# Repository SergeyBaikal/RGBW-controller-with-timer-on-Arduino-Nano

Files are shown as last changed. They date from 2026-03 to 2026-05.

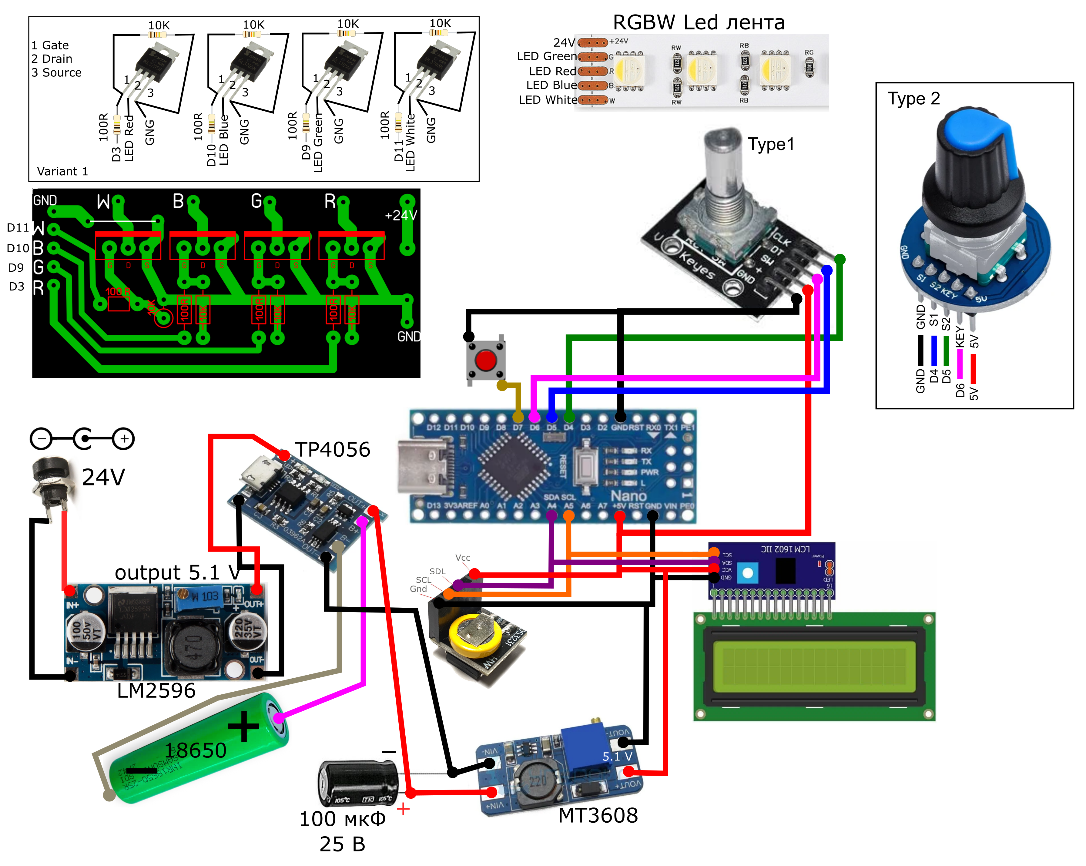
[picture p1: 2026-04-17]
Scheme_with_battery.png

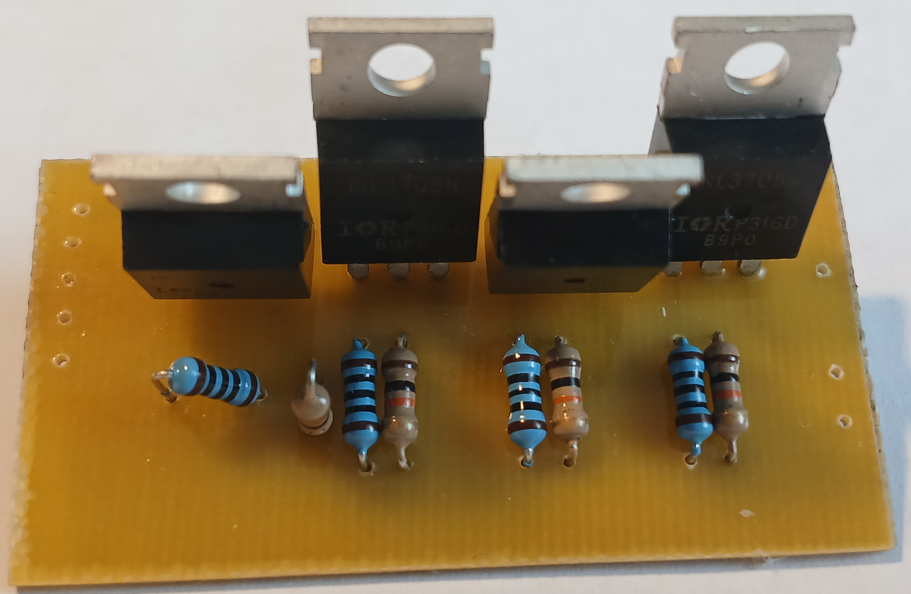
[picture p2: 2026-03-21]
Fig. S1.jpg

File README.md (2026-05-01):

# RGBW controller with timer on Arduino Nano

# 1. ОПИСАНИЕ УСТРОЙСТВА

Данное устройство предназначено для управления RGBW светодиодной лентой (12-24В) по заранее заданной программе. Контроллер автоматически меняет цвета ленты (Красный, Зеленый, Синий, Белый) в заданной последовательности и с заданной длительностью, основываясь на показаниях встроенных часов реального времени (RTC).

**Основные возможности:**
*   Автоматическая смена 4-х цветов (RED, GREEN, BLUE, WHITE) и выключения (Темнота «DARK») по расписанию.
*   Возможность пропуска ненужных шагов (SKIP).
*   Раздельная регулировка яркости для каждого цвета (0-255).
*   Работа циклически или однократно.
*   Интуитивное управление с помощью энкодера.
*   LCD 1602 дисплей с настраиваемым отключением подсветки.
*   Сохранение всех настроек в энергонезависимую память (EEPROM).
*   Высокая настраиваемая частота ШИМ (до 31.2 kHz в режиме Phase-correct PWM и до 62.5 kHz в режиме Fast PWM) для исключения мерцания ленты.

# 2. КОМПЛЕКТУЮЩИЕ И СХЕМА ПОДКЛЮЧЕНИЯ

1.  Arduino Nano
2.  LCD 1602 дисплей с I2C адаптером
3.  Модуль часов реального времени DS3231
4.  Энкодер (с кнопкой)
5.  MOSFET для RGBW ленты:
    *   В корпусе TO-220: IRL3705N, IRLZ44N, IRF3205 – лично использованы мной в этом проекте. Можно и другие, смотрите характеристики.
6.  Блок питания: (12/24V). Важно настроить понижающий и повышающий преобразователи при выбранном вольтаже до (!) подключения питания к Arduino (см. рисунок - схему подключения).
7.  Кнопка тактовая для сброса настроек (по необходимости, можно не ставить)
8.  Аккумулятор 18650 (по необходимости, можно не устанавливать)
9.  Плата зарядки аккумулятора TP4056 (по необходимости, можно не устанавливать)
10. Понижающий модуль с 12/24 вольт до 5 вольт (LM2596)
11. Повышающий модуль MT3608. Если хотите сделать чтобы Arduino продолжало работать, когда отключат электроэнергию (по необходимости, можно не устанавливать).

## Схема подключения

**Важно!** Устройство не коммутирует напряжение ленты напрямую. Arduino управляет MOSFET модулем, который, в свою очередь, включает и выключает ленту (т.е. на пине управления будет 0 В или 5 В).

**Таблица 1. Компоненты и пины подключения.**

| Компонент | Пин компонента | Пин Arduino Nano | Примечание |
| :--- | :--- | :--- | :--- |
| **Энкодер** | CLK | D4 | |
| | DT | D5 | |
| | SW (кнопка) | D6 | Подтяжка к GND при нажатии |
| | VCC | 5V | |
| | GND | GND | |
| **DS3231 (RTC)** | SDA (D) | A4 (SDA) | I2C линия |
| | SCL (C) | A5 (SCL) | I2C линия |
| | VCC (+) | 5V | |
| | GND (-) | GND | |
| **LCD I2C** | SDA | A4 (SDA) | I2C линия (общая с RTC) |
| | SCL | A5 (SCL) | I2C линия (общая с RTC) |
| | VCC | 5V | |
| | GND | GND | |
| **Кнопка сброса** | Один контакт | D7 | |
| | Второй контакт | GND | Замыкает на GND при нажатии |
| **MOSFET модуль** | Красный канал (R) | D3 | ШИМ |
| | Зеленый канал (G) | D9 | ШИМ |
| | Синий канал (B) | D10 | ШИМ |
| | Белый канал (W) | D11 | ШИМ |
| | GND | GND | Общий GND с Arduino |

# 3. СБОРКА УСТРОЙСТВА

1.  **Подготовка:** Ознакомьтесь со схемой подключения. Убедитесь, что все компоненты исправны.
2.  **Монтаж:** Соедините все компоненты согласно схеме (см. схему).

# 4. ПРОШИВКА КОНТРОЛЛЕРА

**Важно!** Отключайте внешнее питание при загрузке скетча (блок питания и аккумулятор, если подключены).

1.  Установите Arduino IDE на ваш компьютер.
2.  Установите необходимые библиотеки. Для этого откройте менеджер библиотек (Скетч -> Подключить библиотеку -> Управлять библиотеками...) и найдите/установите следующие библиотеки:
    *   `LiquidCrystal I2C v.2.0.0` (by Frank de Brabander)
    *   `GyverDS3231Min v.1.2.0` (by AlexGyver)
    *   `EncButton v.3.7.4` (by AlexGyver)
    *   `GyverPWM v.1.6.1` (by AlexGyver)
3.  Подключите Arduino Nano к компьютеру через USB.
4.  В Arduino IDE выберите настройки:
    *   **Плата:** Инструменты -> Плата -> Arduino Nano
    *   **Процессор:** Инструменты -> Processor -> ATmega328P (Old Bootloader) (чаще всего)
    *   **Порт:** Инструменты -> Port -> COM... (нужный порт)
5.  Скопируйте код в окно Arduino IDE или откройте файл с расширением `.ino`. Примечание: файл ino должен лежать в одноименной папке, например RGBW.ino должен лежать в папке RGBW. 
6.  Нажмите кнопку **"Загрузить"** (стрелка вправо). Дождитесь окончания загрузки.
7.  Отключить от USB (!) если хотите сразу подключить к блоку питания, но можно не подключать блок питания (и аккумулятор), а потестировать работоспособность энкодера и управление через меню. 

* Чтобы инвертировать поворот энкодера, нужно просто сменить знак:
  `int8_t change = -enc.dir();`  // Сейчас так, можно убрать `-`, чтобы инвертировать

# 5. ПЕРВОЕ ВКЛЮЧЕНИЕ И НАСТРОЙКА

1.  Подайте питание на устройство.
2.  На экране появится заставка с версией прошивки, затем устройство перейдет в главное меню.
3.  **Важно:** если часы реального времени (RTC) не обнаружены, на экране появится ошибка **"RTC ERROR!"**. Проверьте подключение модуля и перезагрузите устройство (путём отключения питания Arduino).
4.  **Текущее время установится автоматически при компиляции, если нет, то:**
    *   Вращайте энкодер, чтобы выбрать пункт **«CLOCK»** в главном меню.
    *   Нажмите на кнопку энкодера, чтобы войти в подменю.
    *   Нажмите еще раз, чтобы начать редактирование часов. Мигающий символ **«H»** показывает, что редактируются часы. Вращайте энкодер для установки значения.
    *   Нажмите кнопку еще раз. Теперь мигает **«M»** — редактируются минуты. Вращайте энкодер.
    *   Нажмите кнопку для подтверждения и выхода из режима редактирования.
5.  Настройте цепочку цветов, их яркость и длительность (см. следующий раздел).

# 6. ИНТЕРФЕЙС И НАВИГАЦИЯ

Управление устройством осуществляется с помощью одного энкодера. Он имеет три основных действия:

*   **ВРАЩЕНИЕ:** Перемещение курсора в меню (вверх/вниз, влево/вправо) или изменение значения параметра.
*   **КОРОТКОЕ НАЖАТИЕ (КЛИК):** Вход в подменю, выбор пункта, начало/конец редактирования параметра.
*   **ДОЛГОЕ НАЖАТИЕ (УДЕРЖАНИЕ ~1 сек):** Выход из текущего меню на уровень выше или остановка активного режима RUN.

**Структура навигации:**
*   **Главное меню:** Список доступных разделов. Вращайте энкодер для выбора пункта, нажмите для входа.
*   **Подменю:** Список параметров внутри раздела. Вращайте энкодер для выбора параметра, нажмите для редактирования.
*   **Режим редактирования:** Значение параметра мигает. Вращайте энкодер для изменения значения. Нажмите для сохранения и выхода.

# 7. ДЕТАЛЬНОЕ ОПИСАНИЕ МЕНЮ

Главное меню состоит из 8 пунктов. Текущий пункт отмечен символом **«>»** слева. В нижней строке отображается следующий пункт для удобства навигации.

### 1. CHAIN (Цепочка цветов)
Здесь настраивается последовательность из 6 шагов.
*   **На экране:** `1#: R` (означает: шаг №1, цвет R).
*   **Редактирование:** Выберите нужный шаг (`1#`-`6#`) вращением, нажмите кнопку. Каждое нажатие меняет цвет по циклу:
    *   `R` (Красный)
    *   `G` (Зеленый)
    *   `B` (Синий)
    *   `W` (Белый)
    *   `D` (DARK, темнота/Выкл)
    *   `X` (SKIP, пропустить шаг)

### 2. BRIGHTNESS (Яркость)
Настройка яркости для каждого цвета индивидуально.
*   **На экране:** `R: 128` (означает: Красный канал, яркость 128).
*   **Редактирование:** Выберите канал (`R`, `G`, `B`, `W`) вращением, нажмите кнопку. Вращайте энкодер для изменения яркости от 0 до 255. Нажмите кнопку для сохранения. Во время редактирования выбранный цвет загорается для визуального контроля.

### 3. TIME (Длительность)
Установка времени работы для каждого шага цепочки.
*   **На экране:** `01:30 1#:R` (означает: 1 час 30 минут для шага №1 цвета R).
*   **Редактирование:** Выберите шаг (`1#`-`6#`) вращением, нажмите кнопку. Начните редактирование часов (мигает **«H»**), вращайте. Нажмите кнопку для перехода к минутам (мигает **«M»**), вращайте. Нажмите кнопку для сохранения.
*   **Примечание:** если для шага в меню «CHAIN» выбран цвет **«X»** (SKIP), его длительность автоматически устанавливается в **«00:00»** и не редактируется.

### 4. REPEAT (Повтор)
Определяет, будет ли цепочка цветов повторяться бесконечно.
*   **На экране:** **«YES»** или **«NO»**.
*   **Редактирование:** Нажмите кнопку для переключения значения.
    *   **«YES»:** после 6-го шага цикл начнется снова с 1-го.
    *   **«NO»:** после завершения 6-го шага работа остановится, лента погаснет.

### 5. CLOCK (Настройка часов)
Установка текущего времени на модуле DS3231.
*   **На экране:** **«SET CLOCK»** и текущее время (например, **«14:25»**).
*   **Редактирование:** Нажмите кнопку для входа в режим редактирования. Аналогично меню «TIME»: сначала редактируются часы, затем минуты.
*   Если RTC не обнаружен, на экране будет **«RTC ERROR»**.

### 6. TEST (Тест)
Быстрая проверка работоспособности ленты и подключения.
*   **Запуск:** Войдите в меню и нажмите кнопку. Устройство по очереди включит на 1 секунду каждый цвет (Красный, Зеленый, Синий, Белый), а затем погаснет.

### 7. DISPLAY (Дисплей)
Настройка таймера подсветки дисплея для экономии энергии.
*   **На экране:** текущий режим.
*   **Редактирование:** Нажмите кнопку для циклического переключения режимов:
    *   **«OFF»:** Подсветка всегда выключена.
    *   **«15MIN»:** Подсветка гаснет через 15 минут бездействия (вращения/нажатия энкодера).
    *   **«1HOUR»:** Подсветка гаснет через 1 час бездействия.
    *   **«ALWAYS»:** Подсветка всегда включена.

### 8. RUN (Запуск)
Основной режим автоматической работы по расписанию.
*   **Запуск:** Войдите в меню. Если RTC исправен, режим запустится автоматически.
*   **Экран RUN:**
    *   Верхняя строка: **«RUN 14:35»** (текущее время).
    *   Нижняя строка: **«01:23 3#:B»** (оставшееся время до смены цвета: 1 час 23 минуты, текущий шаг №3, цвет Синий).
*   **Во время работы:**
    *   **Клик:** показывает на 5 секунд всю цепочку цветов (например, **`R-G-B-W-D-X`**).
    *   **Удержание:** останавливает режим RUN и возвращает в главное меню.

Автоматика сама будет переключать цвета в заданное время, основываясь на времени старта шага и его длительности.

# 8. РЕЖИМ РАБОТЫ ПО РАСПИСАНИЮ (RUN)

Это сердце программы. Алгоритм работы:

1.  При входе в меню **«RUN»** фиксируется текущее время (минуты) как время старта первого шага (Step 1).
2.  Контроллер включает цвет, заданный для Step 1.
3.  Каждую минуту программа проверяет, сколько времени прошло с момента старта шага.
4.  Как только пройденное время становится равным или превышает заданную для этого шага длительность (из меню «TIME»), происходит автоматический переход к следующему шагу.
5.  Шаги, помеченные как **«X»** (SKIP), автоматически пропускаются (на них не тратится время).
6.  Если после завершения последнего шага параметр «REPEAT» установлен в **«YES»**, цикл начинается заново с шага 1. Если **«NO»** — режим RUN останавливается, лента гаснет.

# 9. СБРОС НАСТРОЕК

Если вы хотите вернуть все настройки (цепочку, яркость, время и т.д.) к предустановленным значениям:

1.  Убедитесь, что устройство включено.
2.  Нажмите и удерживайте тактовую кнопку, подключенную к пину D7 (Reset).
3.  На экране появится сообщение **«RESET MEMORY»**.
4.  Отпустите кнопку. Настройки будут сброшены, и устройство перезагрузится.

*Примечание: функцию сброса можно не использовать, я сделал её для себя, чтобы быстро возвращаться к первоначальным параметрам.*

**Предустановленные настройки:**
*   **Цепочка:** R, G, B, W, D, X
*   **Яркость всех цветов:** 128
*   **Длительность всех шагов:** 120 минут (v.1.8.4), 2 минуты (v.1.8.5)
*   **Repeat:** YES
*   **Подсветка:** 15MIN

# 10. ПРИМЕЧАНИЕ

* Проект писался полностью под себя, поэтому, вероятно, вы найдёте много недочётов т.к. выборка тестов небольшая. Тестировал на 2 сборках с новыми деталями. Если есть вопросы, задавайте, в том числе по чистке и улучшению скетча. 
* Кроме того, прикрепляю простой корпус в STL формате (сам корпус и дно), дисплей прикручивается мелкими винтами, остальное можно закрепить термоклеем, ардуино лучше прикрутить на мелкие саморезы, для оперативности загрузки скетчей.
* Посмотрите на рисунок Fig.S1 - нужно развести транзисторы друг относительно друга, чтобы стоки не касались.
* Файл Sprint-Layout так же прикрепляю, если кто-то захочет вытравить платку модуля для MOSFET.
* Писать можно сюда: poet1988@list.ru.
* Благодарю AlexGyver за уроки по ардуино на его сайте.

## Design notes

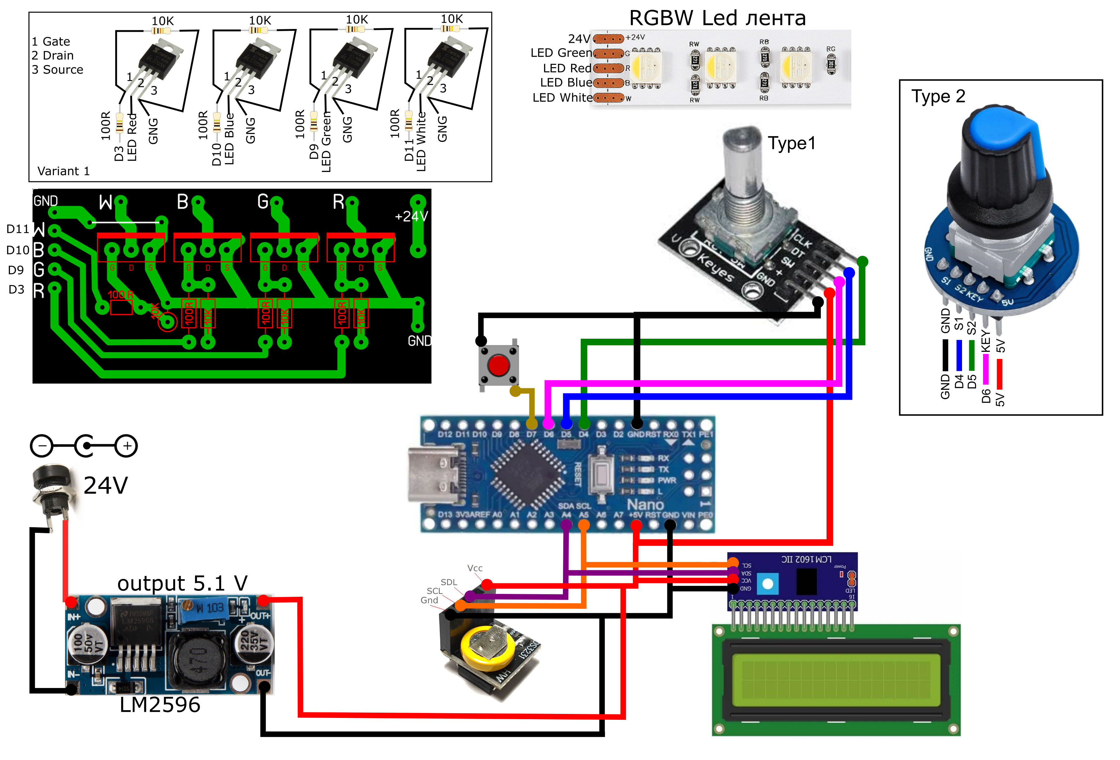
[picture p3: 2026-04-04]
Scheme_without_battery.png

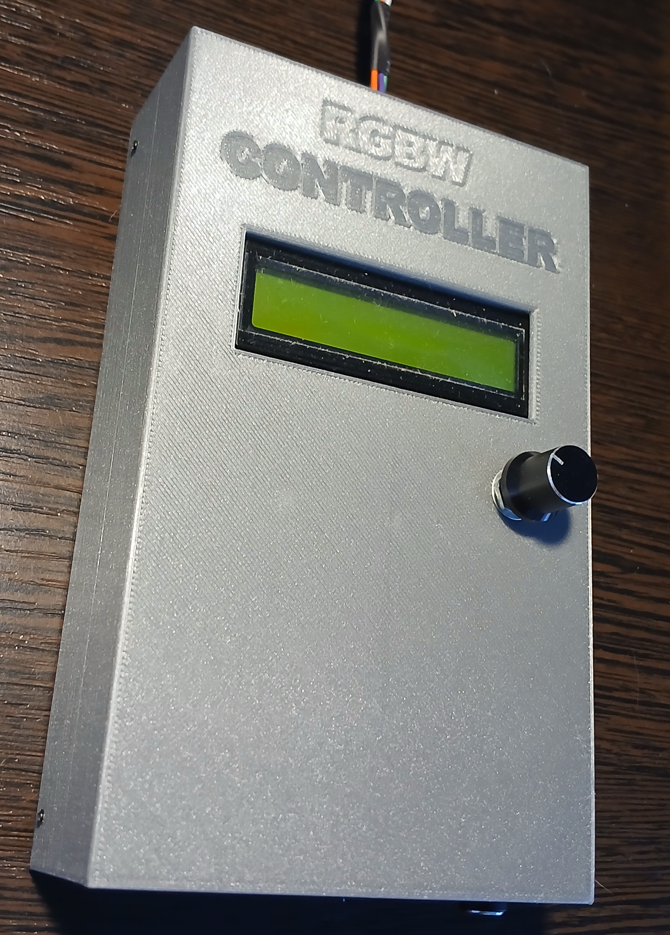
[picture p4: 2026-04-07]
RGBW.jpg

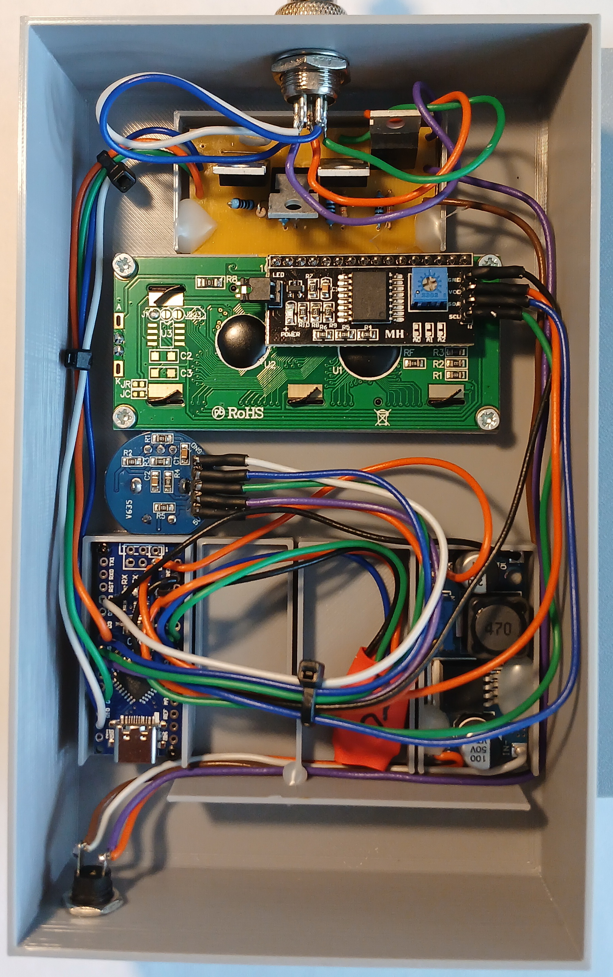
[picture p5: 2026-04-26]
Internal view.jpg

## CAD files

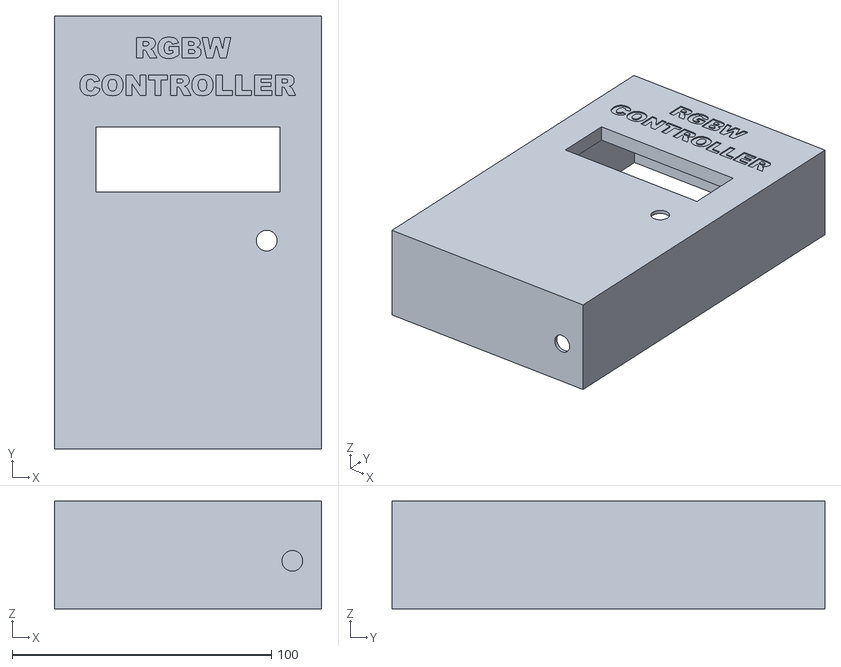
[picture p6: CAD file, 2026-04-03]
RGBW_box_avia.stl
103.0 x 167.0 x 41.5

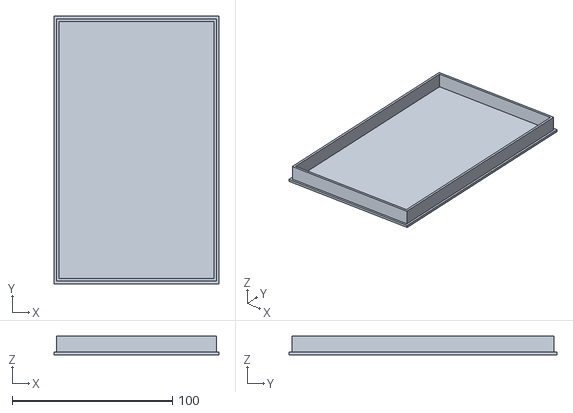
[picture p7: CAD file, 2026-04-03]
Bottom_avia_0.1.stl
103.0 x 167.0 x 11.6

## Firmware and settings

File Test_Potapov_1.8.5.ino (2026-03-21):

/*
  Управление RGBW лентой 24В через Arduino Nano
  с автоматической сменой цвета по расписанию
  Потапов С.А. poet1988@list.ru
  Версия 1.8.5 
  
  Библиотеки:
  - EncButton v3.7.4
  - GyverDS3231Min v1.2+
  - GyverPWM
*/

#include <Wire.h>
#include <LiquidCrystal_I2C.h>
#include <GyverDS3231Min.h>
#include <EncButton.h>
#include <EEPROM.h>
#include <GyverPWM.h>  

// =============== НАСТРОЙКИ КОМПИЛЯЦИИ ===============
#define EB_DEB_TIME 50
#define EB_CLICK_TIME 500
#define EB_HOLD_TIME 600
#define EB_STEP_TIME 200
#define EB_FAST_TIME 30
#define EB_TOUT_TIME 1000

// =============== НАСТРОЙКА ЧАСТОТЫ ШИМ ===============
// Выбор режима ШИМ:
// 0 - Fast PWM (максимальная частота, меньше мерцания)
// 1 - Phase-correct PWM (симметричный, меньше помех)
#define PWM_MODE 0

// Выбор предделителя (частоты):
// 1 - максимальная частота (62.5/31.4 кГц)
// 2 - средняя частота (7.8/4 кГц для Timer1, 8/4 кГц для Timer2)
// 3 - низкая частота (976/490 Гц для Timer1, 2к/980 Гц для Timer2)
#define PWM_PRESCALER 1

/*
   ТАБЛИЦА ЧАСТОТ ШИМ ДЛЯ ARDUINO NANO 
   _________________________________________________________________
  |       | Timer1 (пины 9 и 10) 8 bit | Timer2 (пины 3 и 11) 8 bit|
  |_______|____________________________|___________________________|
  |mode   | Phase-correct | Fast PWM   | Phase-correct | Fast PWM  |
  |_______|_______________|____________|_______________|___________|
  |1      | 31.4 kHz      | 62.5 kHz   | 31.4 kHz      | 62.5 kHz  |
  |2      | 4 kHz         | 7.8 kHz    | 4 kHz         | 8 kHz     |
  |3      | 490 Hz        | 976 Hz     | 980 Hz        | 2 kHz     |
  |_______|_______________|____________|_______________|___________|
  
  
*/

// =============== КОНСТАНТЫ И НАСТРОЙКИ ===============

const char FIRMWARE_VERSION[] = "1.8.5";

// Настройки дисплея
#define LCD_ADDR 0x27
#define LCD_COLS 16
#define LCD_ROWS 2

// Настройки энкодера
#define ENC_CLK 4      // D4 - CLK энкодера
#define ENC_DT 5       // D5 - DT энкодера 
#define ENC_SW 6       // D6 - SW энкодера (кнопка)

// Пины ШИМ
#define PIN_RED 3      // D3 - КРАСНЫЙ канал (Timer2)
#define PIN_GREEN 9    // D9 - ЗЕЛЁНЫЙ канал (Timer1)
#define PIN_BLUE 10    // D10 - СИНИЙ канал (Timer1)
#define PIN_WHITE 11   // D11 - БЕЛЫЙ канал (Timer2)

// Кнопка сброса
#define RESET_BUTTON 7

// Настройки EEPROM
#define EEPROM_SIZE 512
#define EEPROM_MAGIC 0xAA56
#define EEPROM_SAVE_DELAY 5000

#define MAX_STEPS 6
#define TIMEZONE 3
#define ENCODER_TYPE EB_STEP4_LOW

// =============== СТРУКТУРЫ ДАННЫХ ===============

enum Color {
  COLOR_RED,
  COLOR_GREEN,
  COLOR_BLUE,
  COLOR_WHITE,
  COLOR_DARK,
  COLOR_SKIP,
  COLOR_COUNT
};

struct Settings {
  uint16_t magic;
  uint8_t version;
  Color chain[MAX_STEPS];
  uint8_t brightness[4];
  uint16_t durations[MAX_STEPS];
  bool repeat;
  uint8_t backlightTimeout;
};

struct RunState {
  uint8_t currentStep;
  bool active;
  uint32_t stepStartUnix;
  
  RunState() : currentStep(0), active(false), stepStartUnix(0) {}
} runState;

struct Flags {
  uint8_t displayOn : 1;
  uint8_t rtcOk : 1;
  uint8_t settingsChanged : 1;
  uint8_t showChain : 1;
  uint8_t inSubMenu : 1;
  uint8_t editingValue : 1;
  uint8_t rtcMessageShown : 1;
  uint8_t rtcTimeValid : 1;
  uint8_t testRunning : 1;
} flags;

// =============== ГЛОБАЛЬНЫЕ ПЕРЕМЕННЫЕ ===============

LiquidCrystal_I2C lcd(LCD_ADDR, LCD_COLS, LCD_ROWS);
GyverDS3231Min rtc;
EncButton enc(ENC_CLK, ENC_DT, ENC_SW);

Settings settings;

enum MenuState {
  MENU_MAIN,
  MENU_CHAIN,
  MENU_BRIGHTNESS,
  MENU_TIME,
  MENU_CLOCK,
  MENU_REPEAT,
  MENU_DISPLAY,
  MENU_RUN,
  MENU_TEST
};

MenuState currentMenu = MENU_MAIN;
uint8_t menuCursor = 0;
uint8_t subMenuCursor = 0;
uint8_t editPart = 0;
uint8_t editHours = 0;
uint8_t editMinutes = 0;
uint8_t editValue = 0;

// Таймеры
unsigned long displayTimer = 0;
unsigned long saveTimer = 0;
unsigned long rtcCheckTimer = 0;
unsigned long runUpdateTimer = 0;
unsigned long runDisplayTimer = 0;
unsigned long testTimer = 0;
unsigned long userActivity = 0;
unsigned long chainShowTime = 0;

// Для быстрого обновления при редактировании
unsigned long lastEditUpdate = 0;
const unsigned long EDIT_UPDATE_INTERVAL = 50;

// Буферы
char lineBuffer[17];

// Флаги обновления
uint8_t lastHour = 255;
uint8_t lastMinute = 255;
uint16_t lastRemainingTime = 65535;
bool displayChanged = true;
bool partialUpdate = false;
bool forceUpdate = false;

// =============== ПРОТОТИПЫ ФУНКЦИЙ ===============

void initSystem();
void initDisplay();
void initPWM();
void loadSettings();
void saveSettings();
void resetSettings();
bool checkRTC();
void checkUnixTime();

void setColor(Color color, bool forceBrightness = false);
void setChannel(uint8_t pin, uint8_t brightness);
void forceAllPinsOff();
void runTestSequence();

void handleEncoder();
void updateDisplay();
void drawMainMenu();
void drawChainMenu();
void drawBrightnessMenu();
void drawTimeMenu();
void drawClockMenu();
void drawRepeatMenu();
void drawDisplayMenu();
void drawRunScreen();
void drawTestScreen();
void drawPartialRunScreen();
void drawChainOverview();

char colorToChar(Color color);
void formatTime(uint16_t minutes, char* buffer);
uint16_t calculateRemainingTime();

void runScheduler();
void advanceChain();
void startRunMode();
void stopRunMode();

// =============== ИНИЦИАЛИЗАЦИЯ ===============

void setup() {
  Serial.begin(115200);
  Serial.print(F("RGBW Controller v"));
  Serial.println(FIRMWARE_VERSION);
  
  // Инициализация пинов
  pinMode(PIN_RED, OUTPUT);
  pinMode(PIN_GREEN, OUTPUT);
  pinMode(PIN_BLUE, OUTPUT);
  pinMode(PIN_WHITE, OUTPUT);
  
  // Принудительно выключаем все пины
  digitalWrite(PIN_RED, LOW);
  digitalWrite(PIN_GREEN, LOW);
  digitalWrite(PIN_BLUE, LOW);
  digitalWrite(PIN_WHITE, LOW);
  
  pinMode(RESET_BUTTON, INPUT_PULLUP);
  
  // Инициализация ШИМ
  initPWM();
  
  Wire.begin();
  initDisplay();
  
  setStampZone(TIMEZONE);
  
  flags.rtcOk = false;
  flags.rtcTimeValid = false;
  
  if (rtc.begin()) {
    delay(100);
    if (checkRTC()) {
      flags.rtcOk = true;
      checkUnixTime();
    }
  }
  
  enc.setEncType(ENCODER_TYPE);
  
  loadSettings();
  
  runState.active = false;
  runState.currentStep = 0;
  
  unsigned long now = millis();
  displayTimer = now;
  saveTimer = now;
  rtcCheckTimer = now;
  runUpdateTimer = now;
  runDisplayTimer = now;
  userActivity = now;
  
  flags.displayOn = true;
  flags.showChain = false;
  flags.rtcMessageShown = false;
  flags.testRunning = false;
  
  lcd.clear();
  if (flags.rtcOk) {
    lcd.print(F("RTC OK"));
    lcd.setCursor(0, 1);
    lcd.print(F("Unix: "));
    lcd.print(flags.rtcTimeValid ? F("OK") : F("FAIL"));
  } else {
    lcd.print(F("RTC ERROR!"));
  }
  delay(2000);
  
  if (flags.rtcOk && !flags.rtcTimeValid) {
    lcd.clear();
    lcd.print(F("Set build time"));
    rtc.setBuildTime();
    delay(1500);
    checkUnixTime();
  }
  
  lcd.clear();
  flags.rtcMessageShown = true;
  
  // Убеждаемся, что все каналы выключены
  forceAllPinsOff();
  
  Serial.println(F("System initialized"));
}

// =============== ИНИЦИАЛИЗАЦИЯ ШИМ ===============

void initPWM() {
  // Устанавливаем Timer1 (пины 9 и 10) в 8-битный режим
  PWM_TMR1_8BIT();
  
  // Настройка Timer1 (пины 9,10)
  PWM_mode(PIN_GREEN, PWM_MODE);
  PWM_mode(PIN_BLUE, PWM_MODE);
  PWM_prescaler(PIN_GREEN, PWM_PRESCALER);
  PWM_prescaler(PIN_BLUE, PWM_PRESCALER);
  
  // Настройка Timer2 (пины 3,11)
  PWM_mode(PIN_RED, PWM_MODE);
  PWM_mode(PIN_WHITE, PWM_MODE);
  PWM_prescaler(PIN_RED, PWM_PRESCALER);
  PWM_prescaler(PIN_WHITE, PWM_PRESCALER);
  
  // Сбрасываем регистры Timer2 в 0
  OCR2A = 0;
  OCR2B = 0;
  
  // Инициализация всех каналов в 0
  PWM_set(PIN_RED, 0);
  PWM_set(PIN_GREEN, 0);
  PWM_set(PIN_BLUE, 0);
  PWM_set(PIN_WHITE, 0);
  
  // Вывод информации о частотах
  Serial.println(F("=== PWM Configuration ==="));
  Serial.print(F("Mode: "));
  Serial.println(PWM_MODE ? F("Phase-correct") : F("Fast PWM"));
  Serial.print(F("Prescaler: "));
  Serial.println(PWM_PRESCALER);
  
  Serial.println(F("Frequencies:"));
  
  // Timer1 (9,10) - 8-bit
  Serial.print(F("  D9,D10 (Timer1): "));
  if (PWM_MODE == 0) { // Fast PWM
    switch(PWM_PRESCALER) {
      case 1: Serial.println(F("62.5 kHz")); break;
      case 2: Serial.println(F("7.8 kHz")); break;
      case 3: Serial.println(F("976 Hz")); break;
    }
  } else { // Phase-correct
    switch(PWM_PRESCALER) {
      case 1: Serial.println(F("31.4 kHz")); break;
      case 2: Serial.println(F("4 kHz")); break;
      case 3: Serial.println(F("490 Hz")); break;
    }
  }
  
  // Timer2 (3,11)
  Serial.print(F("  D3,D11 (Timer2): "));
  if (PWM_MODE == 0) { // Fast PWM
    switch(PWM_PRESCALER) {
      case 1: Serial.println(F("62.5 kHz")); break;
      case 2: Serial.println(F("8 kHz")); break;
      case 3: Serial.println(F("2 kHz")); break;
    }
  } else { // Phase-correct
    switch(PWM_PRESCALER) {
      case 1: Serial.println(F("31.4 kHz")); break;
      case 2: Serial.println(F("4 kHz")); break;
      case 3: Serial.println(F("980 Hz")); break;
    }
  }
  Serial.println(F("========================"));
}

// =============== ИНИЦИАЛИЗАЦИЯ ДИСПЛЕЯ ===============

void initDisplay() {
  Wire.beginTransmission(LCD_ADDR);
  if (Wire.endTransmission() != 0) {
    Serial.println(F("LCD not found!"));
  }
  
  lcd.init();
  lcd.backlight();
  lcd.clear();
  
  lcd.setCursor(0, 0);
  lcd.print(F("RGBW Controller"));
  lcd.setCursor(0, 1);
  lcd.print(F("v"));
  lcd.print(FIRMWARE_VERSION);
  
  delay(1500);
}

// =============== РАБОТА С EEPROM ===============

void loadSettings() {
  EEPROM.get(0, settings);
  
  if (settings.magic != EEPROM_MAGIC || settings.version != 2) {
    Serial.println(F("Invalid settings, loading defaults"));
    resetSettings();
    return;
  }
  
  Serial.println(F("Settings loaded"));
}

void saveSettings() {
  settings.magic = EEPROM_MAGIC;
  settings.version = 2;
  
  EEPROM.put(0, settings);
  
  Settings verify;
  EEPROM.get(0, verify);
  
  if (memcmp(&settings, &verify, sizeof(Settings)) == 0) {
    flags.settingsChanged = false;
    Serial.println(F("Settings saved"));
  }
}

void resetSettings() {
  settings.magic = EEPROM_MAGIC;
  settings.version = 2;
  
  settings.chain[0] = COLOR_RED;
  settings.chain[1] = COLOR_GREEN;
  settings.chain[2] = COLOR_BLUE;
  settings.chain[3] = COLOR_WHITE;
  settings.chain[4] = COLOR_DARK;
  settings.chain[5] = COLOR_SKIP;
  
  for (int i = 0; i < 4; i++) {
    settings.brightness[i] = 128;
  }
  
  for (int i = 0; i < MAX_STEPS; i++) {
    settings.durations[i] = 120;
  }
  
  settings.repeat = true;
  settings.backlightTimeout = 1;
  
  flags.settingsChanged = true;
  saveSettings();
}

// =============== УПРАВЛЕНИЕ СВЕТОМ ===============

void setColor(Color color, bool forceBrightness) {
  // Сначала выключаем все каналы
  if (color == COLOR_DARK || color == COLOR_SKIP) {
    forceAllPinsOff();
    return;
  }
  
  uint8_t brightness = forceBrightness ? 255 : settings.brightness[color];
  
  // В зависимости от цвета включаем нужный канал
  switch (color) {
    case COLOR_RED:
      setChannel(PIN_RED, brightness);
      setChannel(PIN_GREEN, 0);
      setChannel(PIN_BLUE, 0);
      setChannel(PIN_WHITE, 0);
      break;
      
    case COLOR_GREEN:
      setChannel(PIN_RED, 0);
      setChannel(PIN_GREEN, brightness);
      setChannel(PIN_BLUE, 0);
      setChannel(PIN_WHITE, 0);
      break;
      
    case COLOR_BLUE:
      setChannel(PIN_RED, 0);
      setChannel(PIN_GREEN, 0);
      setChannel(PIN_BLUE, brightness);
      setChannel(PIN_WHITE, 0);
      break;
      
    case COLOR_WHITE:
      setChannel(PIN_RED, 0);
      setChannel(PIN_GREEN, 0);
      setChannel(PIN_BLUE, 0);
      setChannel(PIN_WHITE, brightness);
      break;
      
    default:
      forceAllPinsOff();
      break;
  }
}

void setChannel(uint8_t pin, uint8_t brightness) {
  // Для всех пинов используем PWM_set
  PWM_set(pin, brightness);
  
  // Для Timer2 дополнительно обновляем регистры для надёжности
  if (pin == PIN_RED) {
    OCR2B = brightness;
  } else if (pin == PIN_WHITE) {
    OCR2A = brightness;
  }
}

void forceAllPinsOff() {
  // Выключаем через PWM_set
  PWM_set(PIN_RED, 0);
  PWM_set(PIN_GREEN, 0);
  PWM_set(PIN_BLUE, 0);
  PWM_set(PIN_WHITE, 0);
  
  // Сбрасываем регистры Timer2
  OCR2A = 0;
  OCR2B = 0;
  
  // Дополнительно digitalWrite для гарантии
  digitalWrite(PIN_RED, LOW);
  digitalWrite(PIN_GREEN, LOW);
  digitalWrite(PIN_BLUE, LOW);
  digitalWrite(PIN_WHITE, LOW);
}

void runTestSequence() {
  if (!flags.testRunning) {
    flags.testRunning = true;
    testTimer = millis();
    currentMenu = MENU_TEST;
  }
}

// =============== ПРОВЕРКА RTC ===============

bool checkRTC() {
  Wire.beginTransmission(0x68);
  if (Wire.endTransmission() != 0) return false;
  
  Wire.requestFrom((uint8_t)0x68, (uint8_t)3);
  if (Wire.available() < 3) return false;
  
  uint8_t sec = Wire.read();
  uint8_t min = Wire.read();
  uint8_t hour = Wire.read();
  
  if ((sec & 0x7F) > 0x59) return false;
  if (min > 0x59) return false;
  if ((hour & 0x3F) > 0x23) return false;
  
  return true;
}

void checkUnixTime() {
  uint32_t unixTime = rtc.getUnix();
  flags.rtcTimeValid = (unixTime > 1700000000);
  
  Serial.print(F("Unix time: "));
  Serial.println(unixTime);
}

// =============== ОБРАБОТКА ЭНКОДЕРА ===============
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
void loop() {
  unsigned long now = millis();
  
  // ===== ЭНКОДЕР =====
  enc.tick();
  
  if (enc.turn() || enc.click() || enc.hold()) {
    userActivity = now;
    
    if (!flags.displayOn) {
      flags.displayOn = true;
      lcd.backlight();
      displayChanged = true;
    }
    
    handleEncoder();
    
    if (flags.editingValue) {
      forceUpdate = true;
      lastEditUpdate = now;
    }
  }
  
  // ===== ДИСПЛЕЙ =====
  bool needUpdate = false;
  
  if (flags.editingValue) {
    if (forceUpdate || (now - lastEditUpdate >= EDIT_UPDATE_INTERVAL)) {
      needUpdate = true;
      lastEditUpdate = now;
      forceUpdate = false;
    }
  } else if (now - displayTimer >= 200) {
    needUpdate = true;
    displayTimer = now;
  }
  
  if (needUpdate) {
    if (flags.showChain) {
      if (now - chainShowTime > 5000) {
        flags.showChain = false;
        displayChanged = true;
      }
    }
    
    if (displayChanged) {
      lcd.clear();
      
      if (currentMenu == MENU_RUN && flags.showChain) {
        drawChainOverview();
      } else {
        switch (currentMenu) {
          case MENU_MAIN: drawMainMenu(); break;
          case MENU_CHAIN: drawChainMenu(); break;
          case MENU_BRIGHTNESS: drawBrightnessMenu(); break;
          case MENU_TIME: drawTimeMenu(); break;
          case MENU_CLOCK: drawClockMenu(); break;
          case MENU_REPEAT: drawRepeatMenu(); break;
          case MENU_DISPLAY: drawDisplayMenu(); break;
          case MENU_RUN: drawRunScreen(); break;
          case MENU_TEST: drawTestScreen(); break;
        }
      }
      
      displayChanged = false;
      partialUpdate = false;
      
    } else if (partialUpdate) {
      if (currentMenu == MENU_RUN) {
        drawPartialRunScreen();
      } else if (currentMenu == MENU_MAIN) {
        lcd.setCursor(0, 0);
        lcd.print(' ');
        lcd.setCursor(0, 1);
        lcd.print(' ');
        lcd.setCursor(0, menuCursor % 2);
        lcd.print('>');
      } else {
        lcd.clear();
        switch (currentMenu) {
          case MENU_BRIGHTNESS: drawBrightnessMenu(); break;
          case MENU_TIME: drawTimeMenu(); break;
          case MENU_CLOCK: drawClockMenu(); break;
          default: break;
        }
      }
      partialUpdate = false;
    }
  }
  
  // ===== СОХРАНЕНИЕ НАСТРОЕК =====
  if (flags.settingsChanged && (now - saveTimer >= EEPROM_SAVE_DELAY)) {
    saveTimer = now;
    saveSettings();
  }
  
  // ===== ПОДСВЕТКА =====
  static unsigned long lastBacklightCheck = 0;
  if (now - lastBacklightCheck >= 1000) {
    lastBacklightCheck = now;
    
    if (flags.displayOn && settings.backlightTimeout > 0 && settings.backlightTimeout < 3) {
      unsigned long timeout = (settings.backlightTimeout == 1) ? 900000 : 3600000;
      if (now - userActivity > timeout) {
        flags.displayOn = false;
        lcd.noBacklight();
      }
    }
  }
  
  // ===== РЕЖИМ RUN =====
  if (currentMenu == MENU_RUN && flags.rtcOk) {
    if (now - runUpdateTimer >= 1000) {
      runUpdateTimer = now;
      runScheduler();
    }
    if (now - runDisplayTimer >= 500) {
      runDisplayTimer = now;
      partialUpdate = true;
    }
  }
  
  // ===== ТЕСТ =====
  if (flags.testRunning) {
    if (now - testTimer >= 1000) {
      testTimer = now;
      
      static uint8_t testStep = 0;
      switch (testStep) {
        case 0:
          lcd.clear();
          lcd.print(F("Test RED"));
          setColor(COLOR_RED, true);
          testStep = 1;
          break;
        case 1:
          lcd.clear();
          lcd.print(F("Test GREEN"));
          setColor(COLOR_GREEN, true);
          testStep = 2;
          break;
        case 2:
          lcd.clear();
          lcd.print(F("Test BLUE"));
          setColor(COLOR_BLUE, true);
          testStep = 3;
          break;
        case 3:
          lcd.clear();
          lcd.print(F("Test WHITE"));
          setColor(COLOR_WHITE, true);
          testStep = 4;
          break;
        case 4:
          forceAllPinsOff();
          flags.testRunning = false;
          currentMenu = MENU_TEST;
          displayChanged = true;
          testStep = 0;
          break;
      }
    }
  }
  
  // ===== ПРОВЕРКА RTC =====
  if (now - rtcCheckTimer >= 60000) {
    rtcCheckTimer = now;
    bool rtcNow = checkRTC();
    if (rtcNow != flags.rtcOk) {
      flags.rtcOk = rtcNow;
      displayChanged = true;
      if (!rtcNow && runState.active) stopRunMode();
    }
  }
  
  // ===== КНОПКА СБРОСА =====
  static bool lastResetState = HIGH;
  bool currentResetState = digitalRead(RESET_BUTTON);
  
  if (lastResetState == HIGH && currentResetState == LOW) {
    delay(50);
    if (digitalRead(RESET_BUTTON) == LOW) {
      lcd.clear();
      lcd.print(F("RESET MEMORY"));
      delay(1000);
      
      resetSettings();
      loadSettings();
      
      lcd.clear();
      displayChanged = true;
    }
  }
  lastResetState = currentResetState;
}

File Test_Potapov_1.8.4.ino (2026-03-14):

/*
  Управление RGBW лентой 24В через Arduino Nano
  с автоматической сменой цвета по расписанию
  Потапов С.А. poet1988@list.ru
  Версия 1.8.4 
*/

#include <Wire.h>
#include <LiquidCrystal_I2C.h>
#include <GyverDS3231Min.h>
#include <EncButton.h>
#include <EEPROM.h>
#include <GyverPWM.h>  

// =============== КОНСТАНТЫ И НАСТРОЙКИ ===============

// Версия прошивки
const char FIRMWARE_VERSION[] = "1.8.4";

// Настройки дисплея
#define LCD_ADDR 0x27
#define LCD_COLS 16
#define LCD_ROWS 2

// Настройки энкодера
#define ENC_CLK 4      // D4 - CLK энкодера
#define ENC_DT 5       // D5 - DT энкодера 
#define ENC_SW 6       // D6 - SW энкодера (кнопка)

// Пины ШИМ
#define PIN_RED 3      // D3 - КРАСНЫЙ канал (Timer2)
#define PIN_GREEN 9    // D9 - ЗЕЛЁНЫЙ канал (Timer1)
#define PIN_BLUE 10    // D10 - СИНИЙ канал (Timer1)
#define PIN_WHITE 11   // D11 - БЕЛЫЙ канал (Timer2)

// Кнопка сброса
#define RESET_BUTTON 7

// =============== НАСТРОЙКА ЧАСТОТЫ ШИМ ===============
 
#define PWM_PRESCALER 1  // 1 - 31.4 кГц, 2 - 4 кГц 
#define PWM_MODE 1       // 1 - Phase-correct PWM, 0 - Fast PWM

// Настройки EEPROM
#define EEPROM_SIZE 512
#define EEPROM_MAGIC 0xAA56
#define EEPROM_SAVE_DELAY 5000

// Максимальное количество шагов
#define MAX_STEPS 6

// Тип энкодера
#define ENCODER_TYPE EB_STEP4_LOW

// =============== СТРУКТУРЫ ДАННЫХ ===============

enum Color {
  COLOR_RED,
  COLOR_GREEN,
  COLOR_BLUE,
  COLOR_WHITE,
  COLOR_DARK,
  COLOR_SKIP,
  COLOR_COUNT
};

struct Settings {
  uint16_t magic;
  uint8_t version;
  Color chain[MAX_STEPS];
  uint8_t brightness[4];  // 0-255 для всех каналов
  uint16_t durations[MAX_STEPS];
  bool repeat;
  uint8_t backlightTimeout;
};

struct RunState {
  uint8_t currentStep;
  bool active;
  
  RunState() : currentStep(0), active(false) {}
} runState;

struct Timer {
  unsigned long lastTick;
  unsigned long interval;
  
  Timer() : lastTick(0), interval(0) {}
  
  void setInterval(unsigned long ms) {
    interval = ms;
  }
  
  void reset() {
    lastTick = millis();
  }
  
bool check() {
  unsigned long currentMillis = millis();
  if (currentMillis - lastTick >= interval) {
    lastTick = currentMillis;
    return true;
  }
  return false;
}
};

struct Flags {
  uint8_t displayOn : 1;
  uint8_t rtcOk : 1;
  uint8_t settingsChanged : 1;
  uint8_t showChain : 1;
  uint8_t inSubMenu : 1;
  uint8_t editingValue : 1;
  uint8_t chainDisplayRequest : 1;
  uint8_t rtcMessageShown : 1;
} flags;

struct StepTime {
  uint32_t startUnix;
  uint16_t duration;
  
  StepTime() : startUnix(0), duration(0) {}
} stepTime;
// =============== ГЛОБАЛЬНЫЕ ПЕРЕМЕННЫЕ ===============

LiquidCrystal_I2C lcd(LCD_ADDR, LCD_COLS, LCD_ROWS);
GyverDS3231Min rtc;
EncButton enc(ENC_CLK, ENC_DT, ENC_SW);

Settings settings;

enum MenuState {
  MENU_MAIN,
  MENU_CHAIN,
  MENU_BRIGHTNESS,
  MENU_TIME,
  MENU_CLOCK,
  MENU_REPEAT,
  MENU_DISPLAY,
  MENU_RUN,
  MENU_TEST
};

MenuState currentMenu = MENU_MAIN;
uint8_t menuCursor = 0;
uint8_t subMenuCursor = 0;
uint8_t editPart = 0;
uint8_t editHours = 0;
uint8_t editMinutes = 0;
uint8_t editValue = 0;

// Системные таймеры
Timer displayTimer;
Timer saveTimer;
Timer rtcCheckTimer;
Timer runUpdateTimer;
Timer runDisplayTimer;

// Таймер для показа цепочки 
unsigned long chainShowTime = 0;

// Буферы
char displayBuffer[17];
char lineBuffer[17];

// Флаги обновления
uint8_t lastMenuCursor = 255;
uint8_t lastSubMenuCursor = 255;
uint8_t lastHour = 255;
uint8_t lastMinute = 255;
uint16_t lastRemainingTime = 65535;
bool displayChanged = true;
bool partialUpdate = false;

// Для отслеживания активности энкодера
unsigned long lastEncoderActivity = 0;
bool encoderActive = false;

// =============== НОВАЯ ПЕРЕМЕННАЯ ДЛЯ ПОДСВЕТКИ ===============
unsigned long lastUserActivity = 0;  // Время последнего действия пользователя

// =============== ПРОТОТИПЫ ФУНКЦИЙ ===============

void initSystem();
void initDisplay();
void initPWM();
void loadSettings();
void saveSettings();
void resetSettings();
bool checkRTC();

void setColor(Color color, bool forceBrightness = false);
void setChannel(uint8_t pin, uint8_t brightness);
void forceAllPinsOff();
void runTestSequence();

void handleEncoder();
void encoderTick();
void updateDisplay();
void drawMainMenu();
void drawChainMenu();
void drawBrightnessMenu();
void drawTimeMenu();
void drawClockMenu();
void drawRepeatMenu();
void drawDisplayMenu();
void drawRunScreen();
void drawTestScreen();
void drawPartialRunScreen();
void drawChainOverview();

char colorToChar(Color color);
const char* colorToString(Color color);
void formatTime(uint16_t minutes, char* buffer);
uint32_t getCurrentMinutes();
uint16_t calculateRemainingTime();

void runScheduler();
void advanceChain();
void startRunMode();
void stopRunMode();
void handleBacklight();

// =============== НОВЫЕ ФУНКЦИИ ОБРАБОТКИ ЭНКОДЕРА ===============

void handleMainMenuTurn(int8_t change) {
  menuCursor = (menuCursor + change + 8) % 8;
}

void handleSubMenuTurn(int8_t change) {
  if (currentMenu == MENU_CHAIN || currentMenu == MENU_TIME) {
    subMenuCursor = (subMenuCursor + change + MAX_STEPS) % MAX_STEPS;
  } else if (currentMenu == MENU_BRIGHTNESS) {
    subMenuCursor = (subMenuCursor + change + 4) % 4;
  }
}

void handleEditTurn(int8_t change) {
  if (currentMenu == MENU_CLOCK || currentMenu == MENU_TIME) {
    if (editPart == 0) {
      if (currentMenu == MENU_CLOCK) {
        editHours = (editHours + change + 24) % 24;
      } else {
        editHours = (editHours + change + 100) % 100;
      }
    } else {
      editMinutes = (editMinutes + change + 60) % 60;
    }
  } else if (currentMenu == MENU_BRIGHTNESS) {
    editValue = constrain(editValue + change, 0, 255);
    
    if (flags.editingValue) {
      // Обновляем яркость выбранного канала в реальном времени
      switch (subMenuCursor) {
        case 0:
          setChannel(PIN_RED, editValue);
          break;
        case 1:
          setChannel(PIN_GREEN, editValue);
          break;
        case 2:
          setChannel(PIN_BLUE, editValue);
          break;
        case 3:
          setChannel(PIN_WHITE, editValue);
          break;
      }
    }
  }
}

// =============== РЕАЛИЗАЦИЯ ФУНКЦИЙ ===============
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

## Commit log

2026-03-14 Скетч
2026-03-14 Схема подключения
2026-03-14 MOSFET модуль
2026-03-14 Корпус в STL для 3D печати
    [RGBW_box.stl]
2026-03-14 Дно корпуса в STL для 3D печати
    [RGBW_bottom.stl]
2026-03-14 Схема_подключения
2026-03-14 Update README.md
    int8_t change = -enc.dir(); реализовано инвертирование
2026-03-14 Update README.md
    инвертирование
2026-04-03 Корпус для контроллера
    [Bottom_avia_0.1.stl, RGBW_box_avia.stl]
2026-04-07 Внешний вид устройства/Appearance of the device
